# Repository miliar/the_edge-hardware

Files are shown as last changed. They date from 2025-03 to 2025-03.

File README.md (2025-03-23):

# The Edge - Hardware

This repository contains the hardware implementation of The Edge, a BLE-enabled weight sensor designed specifically for climbing training.

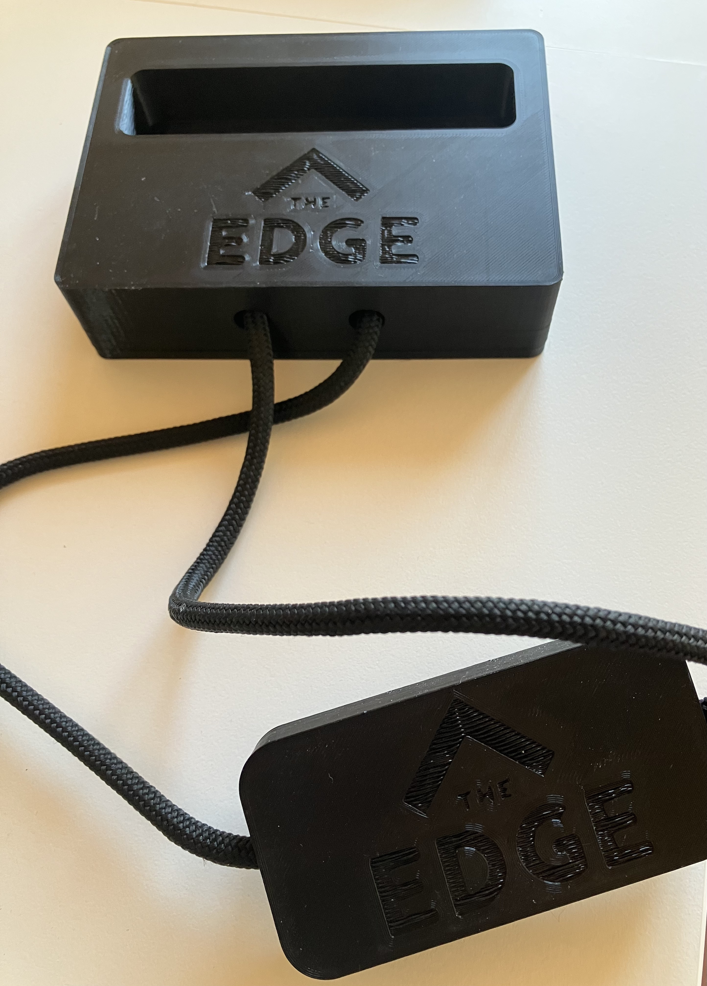
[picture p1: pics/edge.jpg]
The Edge Device


## Project Overview

```mermaid
graph LR
    A[The Edge Hardware] --> |BLE| B[The Edge - Climbing Game]
    subgraph Hardware
        C[Load Cell Sensor] --> A
        E[ESP32-S3 Controller] --> A
    end
    subgraph Mobile App
        B --> F[Game Interface]
        B --> G[Training Stats]
        B --> H[Level Editor]
    end
```

## Project Structure

- [/board](board/README.md) - Hardware assembly instructions and component list
- [/microcontroller](microcontroller/README.md) - Firmware implementation and setup guide
- [/python_cli_app](python_cli_app/README.md) - Test utility (for development use)

## Mobile Application

The Edge hardware connects to "The Edge - Climbing Game" mobile application (available for iOS and Android), which transforms your climbing training into an interactive gaming experience. The app features real-time strength feedback, a progressive level system, and custom level creation capabilities, allowing you to turn training protocols into engaging challenges.

### App Demo

Check out the app in action:

<a href="https://youtube.com/shorts/Y2iQzmk7Qgc" target="_blank">
    
</a>

### App Screenshots

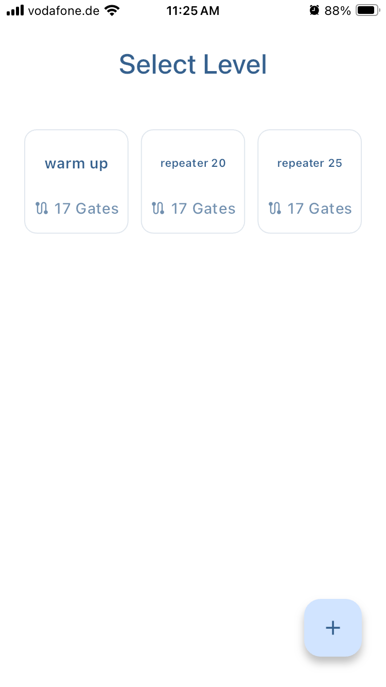
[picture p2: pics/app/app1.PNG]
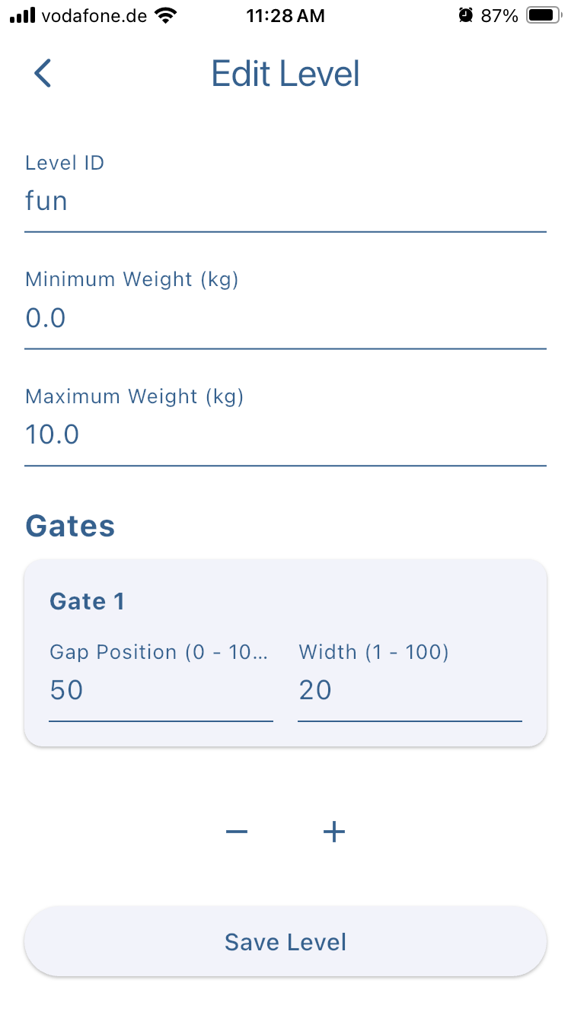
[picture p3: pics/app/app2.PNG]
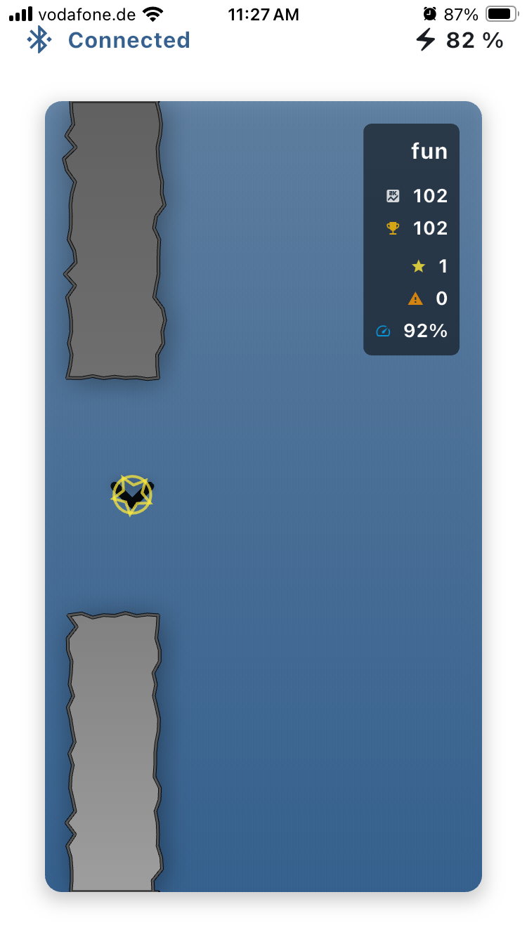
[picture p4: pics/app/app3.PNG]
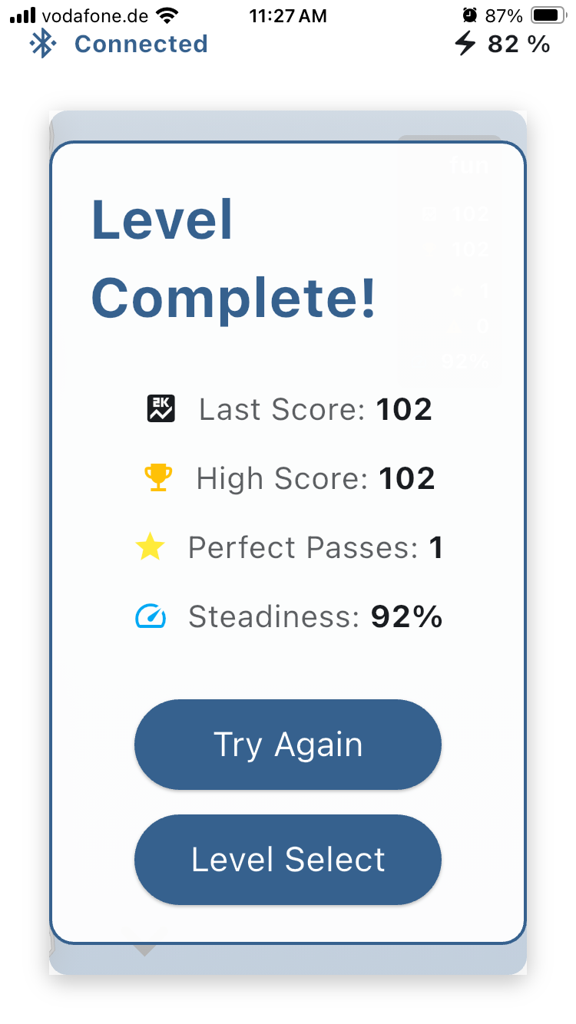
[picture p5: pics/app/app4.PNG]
   

## Getting Started

1. Follow the [hardware assembly guide](board/README.md) to build the device
2. Set up the [microcontroller firmware](microcontroller/README.md)
3. Install The Edge - Climbing Game from your device's app store:

   | App Store | Play Store |
   |:-:|:-:|
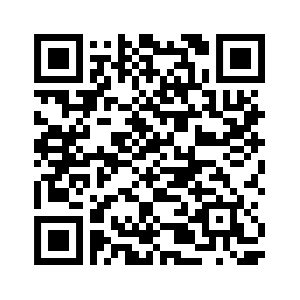
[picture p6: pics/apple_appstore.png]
App Store QR Code
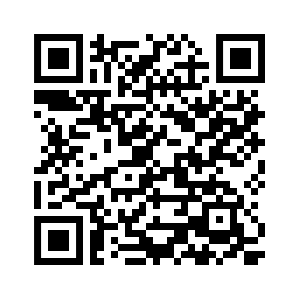
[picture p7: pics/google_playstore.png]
Play Store QR Code
   |  |  |

4. Connect the app to your Edge hardware via Bluetooth
5. Start training!

## Repository Contents

- `board/` - 3D models, assembly instructions, and parts list
- `microcontroller/` - CircuitPython firmware and configuration
- `pics/` - Project documentation images
- `python_cli_app/` - Test utility (for development use)

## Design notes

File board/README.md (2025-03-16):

# Project Components

## Required Parts

- QT Py S3 8MB (No PSRAM)
  - [Purchase Link](https://www.adafruit.com/product/5426)
  - [Pinout Documentation](https://learn.adafruit.com/adafruit-qt-py-esp32-s3/pinouts)

  

- LiPo Backpack
  - [Purchase Link](https://www.adafruit.com/product/5397)
  - [Pinout Documentation](https://learn.adafruit.com/adafruit-qt-py-charger-bff/pinouts)

  

- 2x3 2.54mm SMD Female Connector

  

- NAU7802 ADC
  - [Purchase Link](https://www.adafruit.com/product/4538)
  - [Documentation](https://learn.adafruit.com/adafruit-nau7802-24-bit-adc-stemma-qt-qwiic/python-circuitpython)
  - [Example Code](https://github.com/adafruit/CircuitPython_NAU7802/blob/main/examples/nau7802_simpletest.py)

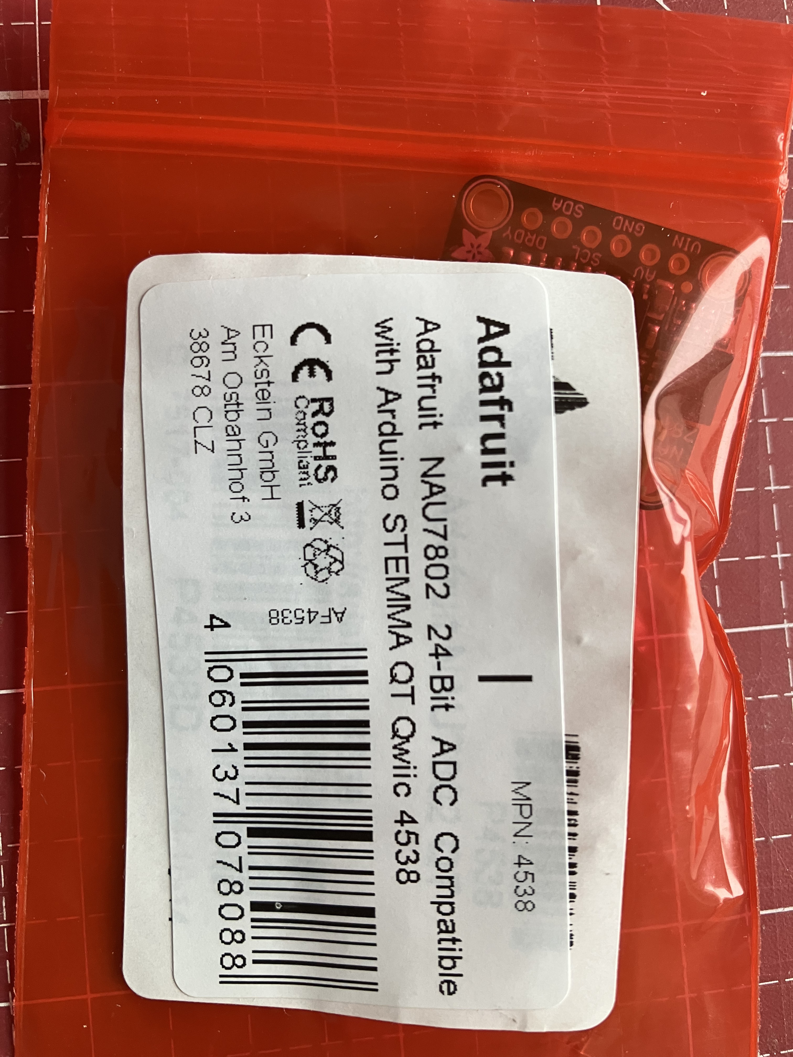
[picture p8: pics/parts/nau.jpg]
  

- LiPo Battery
  - Specifications: 3.7V 350mAh with JST-PHR-2 Connector (LP552035)

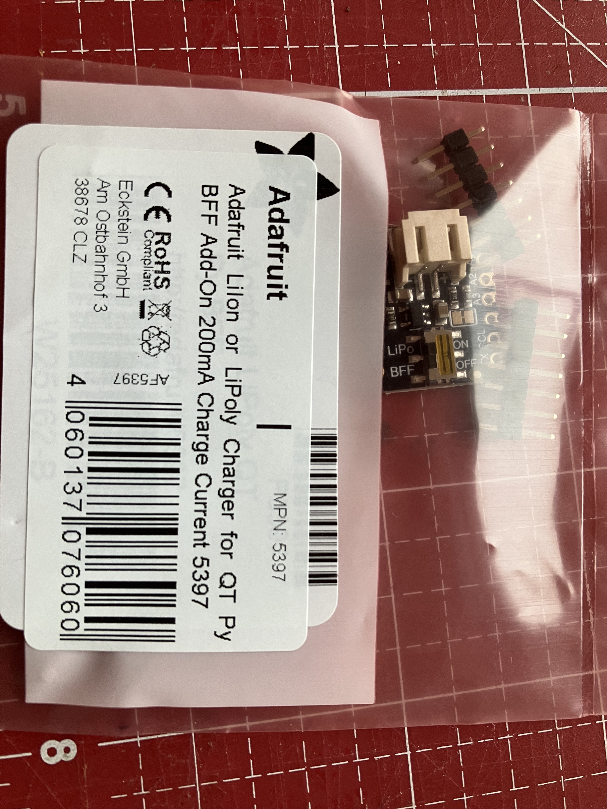
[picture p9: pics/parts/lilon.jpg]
  

- Load Cell
  - Specifications: 25mm 0-200kg (Model: cn1501541594)
  - Manufacturer: XNQ Electric Company Store
  - [Purchase Link](https://www.aliexpress.com/item/33014551751.html)

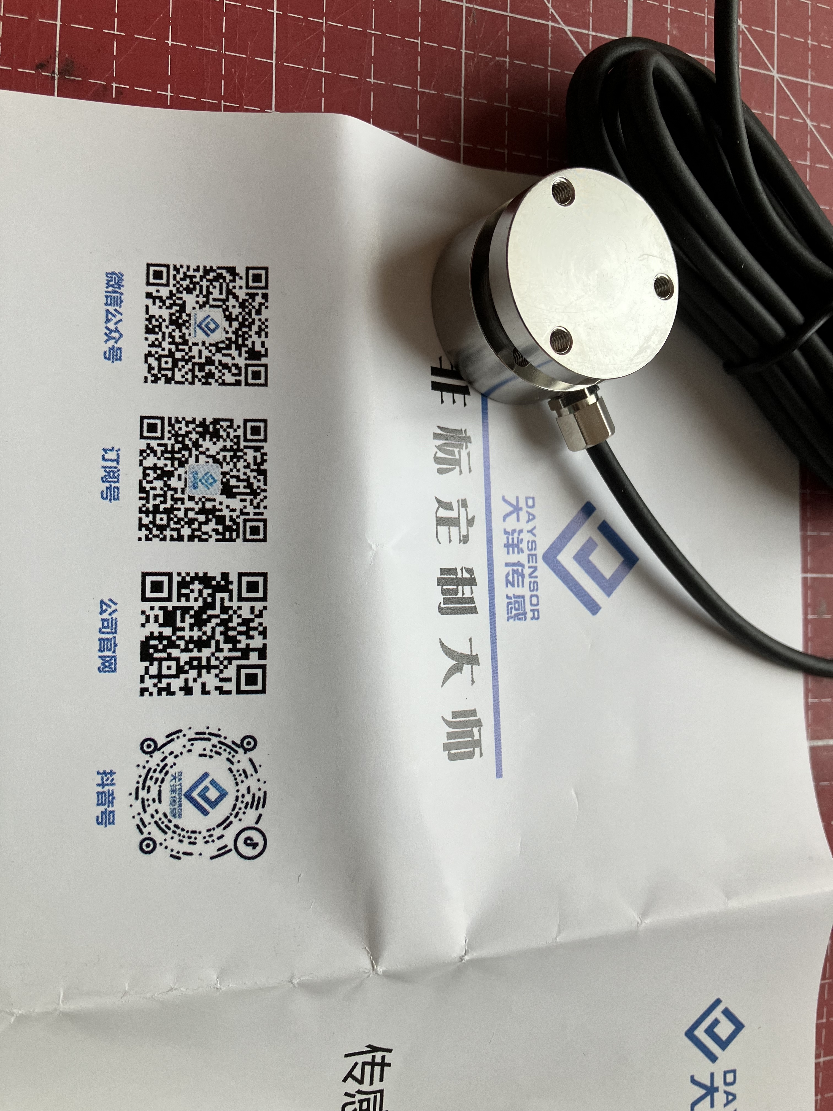
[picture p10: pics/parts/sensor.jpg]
  

- 3x M3 10mm Screws

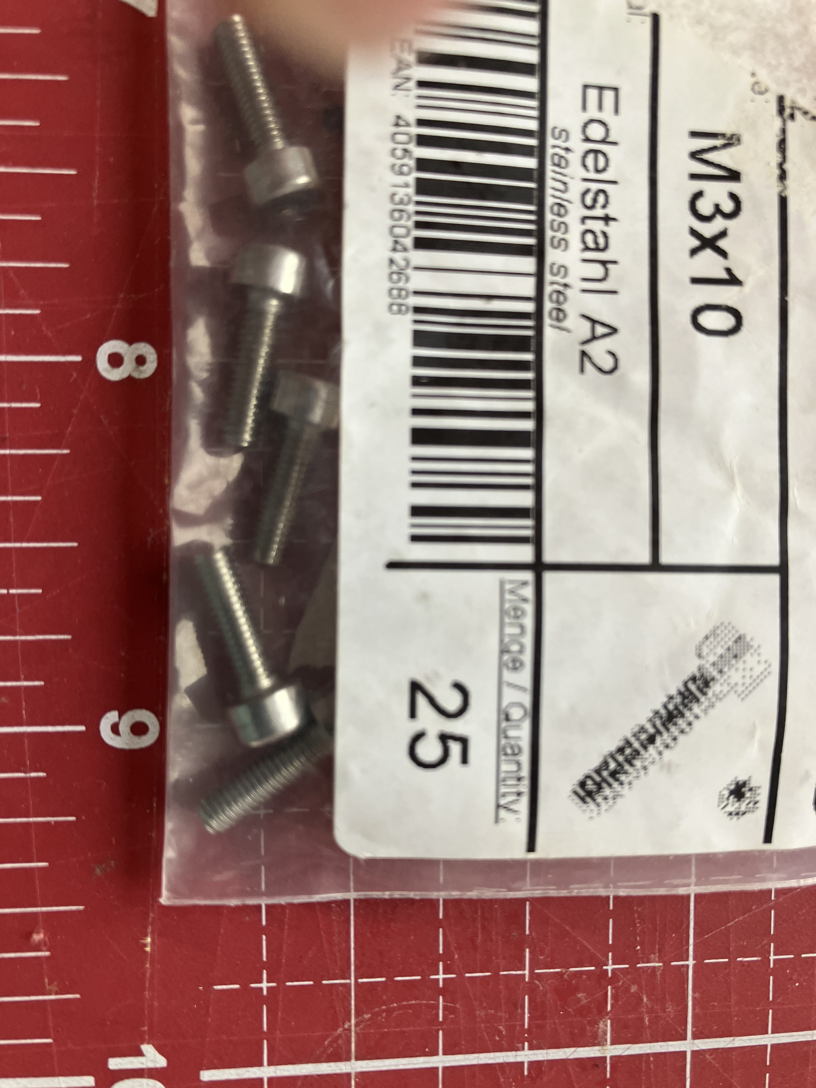
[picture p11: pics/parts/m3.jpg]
  

- STEMMA QT/Qwiic JST SH 4-Pin Cable (≥50mm)

  

- USB-C Connector (7x12x26mm)
  - [Purchase Link](https://www.amazon.de/dp/B0BNNJ5RTG)

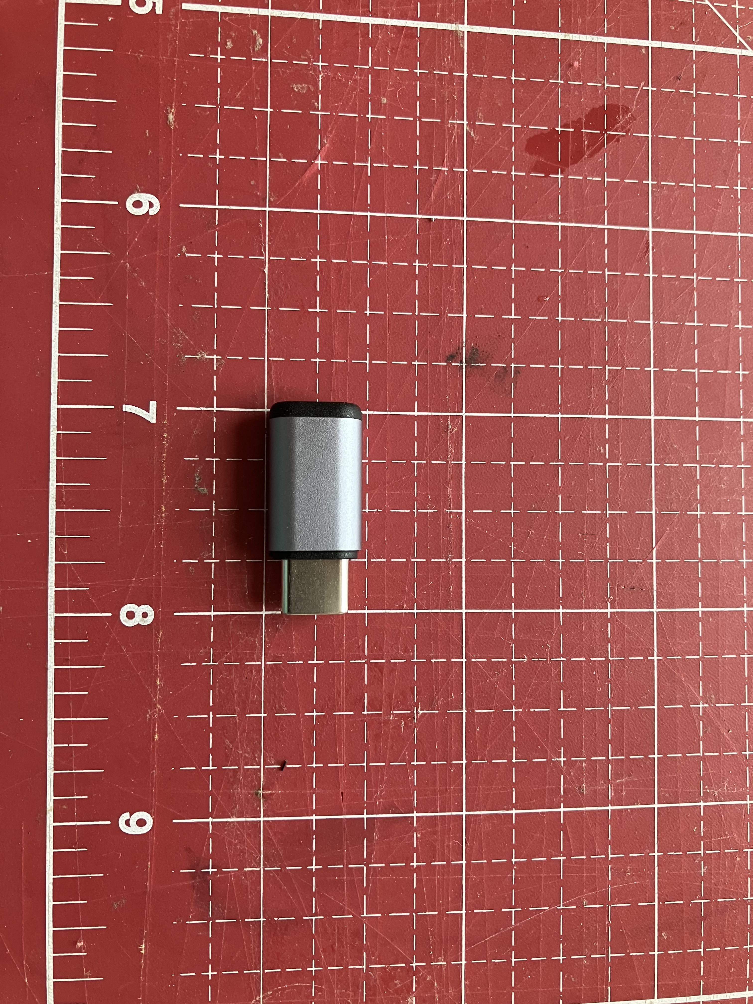
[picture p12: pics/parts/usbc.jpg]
  

- Rope (6mm diameter, ca 1m length)

- Slide Switch with Cables
  - [Purchase Link](https://eckstein-shop.de/PololuMiniSlideSwitch3A3-Pin2CSPDT2C03A3-PackEN)

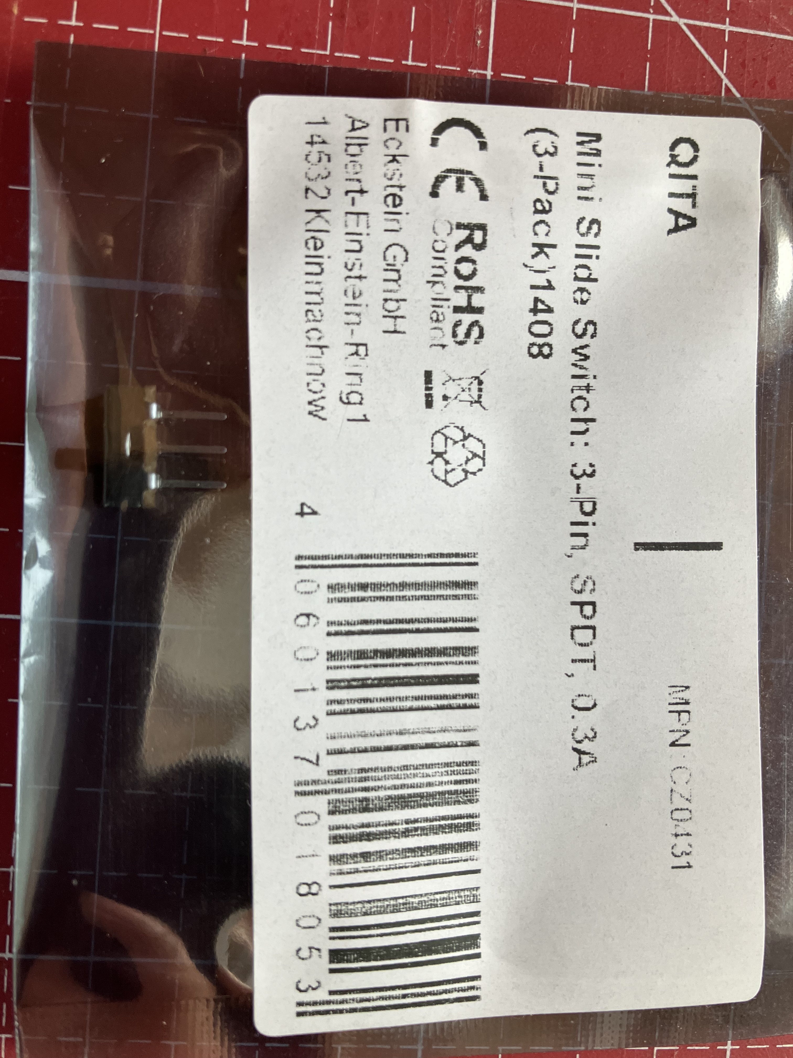
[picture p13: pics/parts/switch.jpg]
  

- 4x Screws (3x12mm)

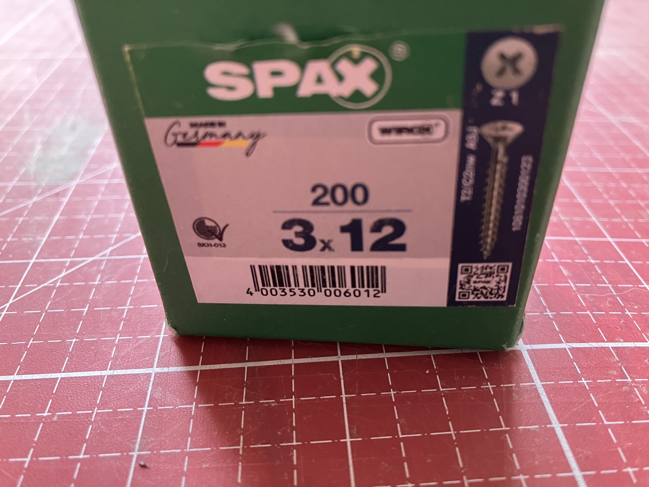
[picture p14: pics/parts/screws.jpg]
  

- 3D Printed Parts in PETG:
  - Use 0.26 mm layer height, 4 perimeters, 50 percent infill
  - Set bridge angle to 90 degrees
  - Enable support for the edge

  

## Board Assembly Instructions

### Soldering Steps
1. Remove the existing switch from the LiPo backpack using hot air (350°C)
2. Solder the 3x2 female connector onto the board using hot air or reflow soldering

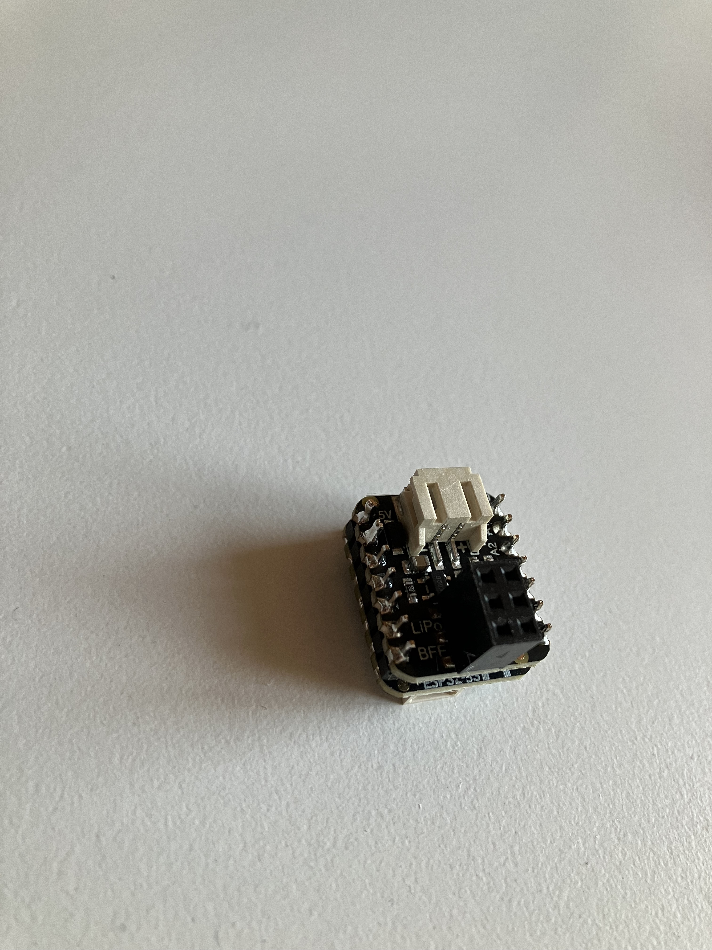
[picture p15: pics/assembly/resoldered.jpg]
   

3. Solder the LiPo backpack to the QT Py S3
4. Prepare two 4cm cables with crimped ends and connect them between the 3x2 connector and the slide switch

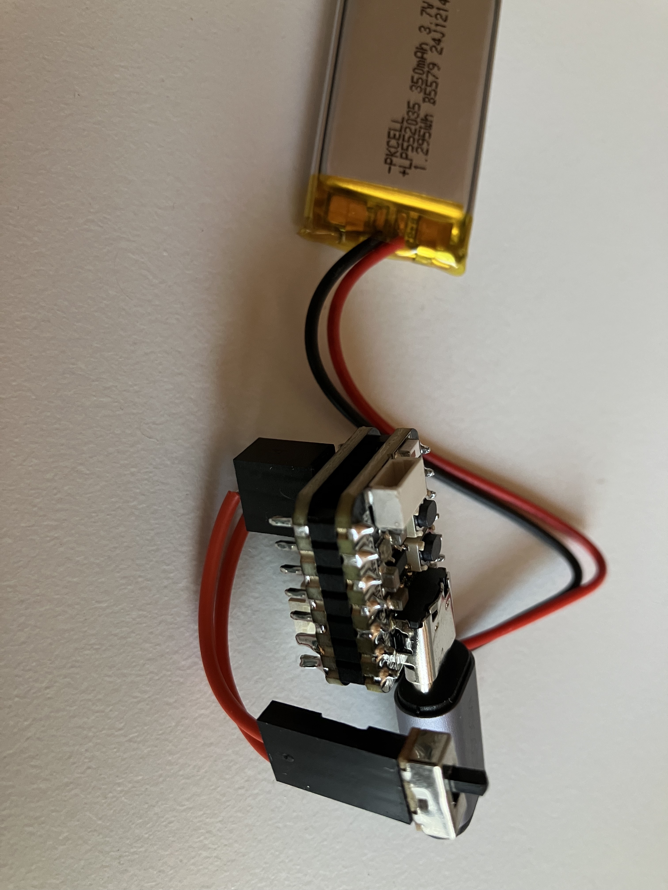
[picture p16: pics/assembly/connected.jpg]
   

### Sensor Cable Preparation
1. Cut the load cell sensor cable to 7cm length
2. Carefully remove the outer insulation and shielding
3. Strip approximately 2cm of insulation from each of the inner cables
4. Neatly twist and roll up the exposed cable ends to prevent fraying
5. Connect the prepared cables to the corresponding terminals on the NAU7802 ADC board

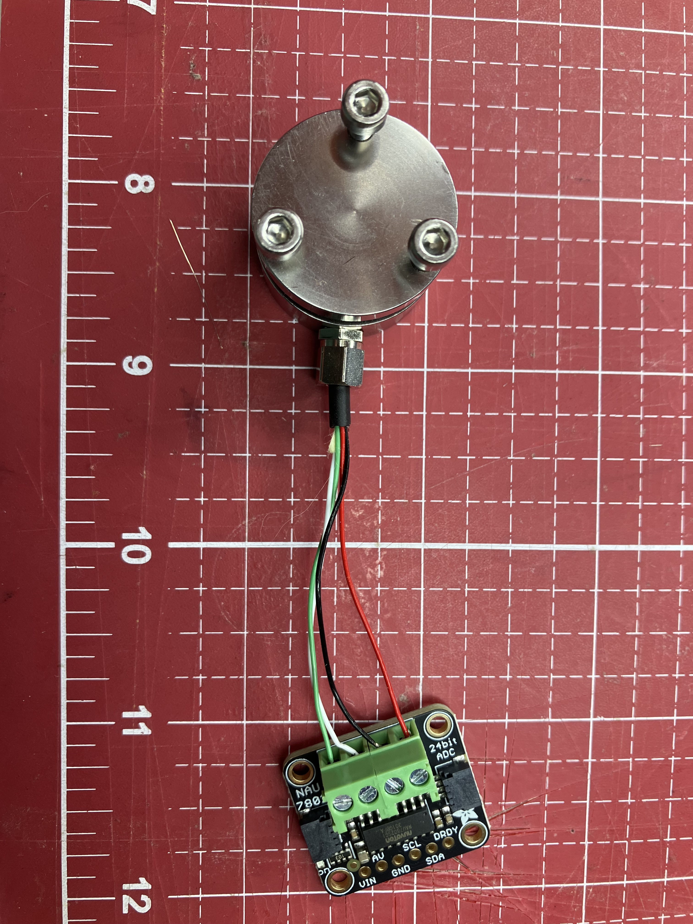
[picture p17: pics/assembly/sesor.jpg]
   

### Final Assembly
1. Insert the 3x M3 10mm screws into the load cell sensor mounting holes to secure the rope
2. Connect the NAU7802 to the QT Py using the STEMMA QT/Qwiic cable
3. Apply adhesive to mount the USB-C connector and slide switch in their designated positions
4. Ensure all components are securely mounted and connections are tight

   

### Info
- Battery Testing Results
  - Voltage: 2.9V under load, 3.6V from USB
  - Operating Time: 3.5 hours
  - Deep Sleep Mode: Battery did only last ~10 hours, so not used
- Adafruit QT Py ESP32-S3 Compatibility:
  - 4MB Flash 2MB PSRAM version not supported ("`no module named _bleio`")
  - Only 8MB No PSRAM version is supported
  - [Compatibility Matrix](https://docs.circuitpython.org/en/latest/shared-bindings/support_matrix.html)

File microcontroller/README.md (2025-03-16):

# Microcontroller Setup Guide

## Initial Setup
1. Factory reset the device
2. Install UF2 bootloader
   - Follow [QT Py ESP32-S3 CircuitPython Guide](https://learn.adafruit.com/adafruit-qt-py-esp32-s3/circuitpython-2)
   - Use [Adafruit Web Serial ESPTool](https://adafruit.github.io/Adafruit_WebSerial_ESPTool/) for flashing

## File Deployment
Copy all files from the `microcontroller/` directory to the device, **excluding** the `setup_circuitpython/` folder.

## Directory Structure
```
microcontroller/
├── code.py                 # Main program file
├── ble_json_service.py     # BLE service implementation
├── config.json             # User configuration file
├── default_config.json     # Default configuration file
└── lib/                    # Required libraries
    ├── adafruit_ble/
    ├── adafruit_bus_device/
    ├── adafruit_register/
    ├── adafruit_pixelbuf.mpy
    ├── cedargrove_nau7802.mpy
    └── neopixel.mpy
```

## Operation Guide

### Serial Console Output
To monitor the serial output while usb-c connected:

1. Find the device ID:
```bash
ls /dev/tty.*
```

2. Connect to the serial console:
```bash
screen [device_id]
```

For more information on using the serial console, see the [CircuitPython Advanced Serial Console Guide](https://learn.adafruit.com/welcome-to-circuitpython/advanced-serial-console-on-mac-and-linux)

### LED Status Indicators
The onboard NeoPixel LED indicates the device's current status:
- Red: Error state or initializing
- Yellow: Waiting for BLE connection
- Green: Connected to a BLE device

### Sensor Functionality
The device provides two sensor measurements:
1. **Weight Sensor**: Uses the NAU7802 load cell amplifier to measure weight. The raw values are averaged over multiple samples (configurable) and scaled according to the configuration.
2. **Voltage Sensor**: Reads analog voltage from pin A2, converts it to a percentage based on configured offset and scale factors.

### BLE Service
The device advertises a custom BLE service with the following characteristics:

1. **Sensors Characteristic** (Read-only)
   - UUID: 528ff74b-fdb8-444c-9c64-3dd5da4135ae
   - Provides real-time sensor data in JSON format:
     ```json
     {
       "weight": <value>,
       "voltage": "<percentage>%"
     }
     ```

2. **Settings Characteristic** (Read/Write)
   - UUID: e077bdec-f18b-4944-9e9e-8b3a815162b4
   - Allows reading and updating device settings

### Configuration
The device uses a configuration file (`config.json`) with fallback to `default_config.json`. Configuration options include:
- `device_name`: BLE advertisement name
- `weight_samples`: Number of samples to average for weight measurement
- `weight_scale_factor`: Scaling factor for weight measurements
- `voltage`: Configuration for voltage sensor:
  - `offset`: Voltage reading offset
  - `scale_factor`: Voltage scaling factor

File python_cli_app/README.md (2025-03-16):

# Python CLI Application Guide
This is a test utility for The Edge hardware that allows you to:
- Scan for available Edge devices
- Connect to a selected device
- Monitor real-time weight measurements
- View battery status
- Track maximum weight (high score)

## Running the Application
```bash
python python_cli_app/ble_json_central.py
```

## Example Output
```
Scanning for Edge devices...
Found device: myedgedewood
Services: <BoundServiceList: 51ad213f-e568-4e35-84e4-67af89c79ef0>
Found device: myedgedevice
Services: <BoundServiceList: 51ad213f-e568-4e35-84e4-67af89c79ef0>

Available devices:
1: myedgedewood
2: myedgedevice

Select device (1-2) or 'r' to rescan: 2
Connected!
{'voltage': '75 %', 'weight': 1566}
{'voltage': '77 %', 'weight': 2344}
{'voltage': '76 %', 'weight': 3869}
{'voltage': '76 %', 'weight': 5126}
{'voltage': '76 %', 'weight': 5362}
{'voltage': '77 %', 'weight': 3700}
{'voltage': '76 %', 'weight': 1503}
High score: 6.37 kg
Last score: 5.126 kg
Power: 77 %
```

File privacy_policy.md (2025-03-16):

# Privacy Policy

Last updated: March 14, 2025

## Introduction

This Privacy Policy describes how your data is handled when using my app. I am committed to protecting your privacy and being transparent about my practices.

## Information Collection

I do not collect, store, or transmit any personal information. All data generated while using the app (such as game progress and settings) is stored locally on your device only and is not transmitted to any external servers.

## Device Permissions

### Bluetooth Access
The app requires Bluetooth permission to connect to compatible hardware devices. This connection is used solely for device communication and no Bluetooth-related data is collected or stored beyond the current session.

## Data Storage

- All app data is stored locally on your device
- No data is transmitted to external servers
- No analytics or usage data is collected
- No crash reports are collected
- No third-party services are used

## Changes to Data

Since all data is stored locally on your device, you can clear the app's data through your device's settings at any time.

## Children's Privacy

My app does not knowingly collect any personal information from anyone, including children under the age of 13.

## Third-Party Services

I do not use any third-party services, analytics, or tracking tools.

## Changes to Privacy Policy

I may update this Privacy Policy from time to time. I will notify you of any changes by posting the new Privacy Policy on this page and updating the "Last updated" date at the top.

## Contact

If you have any questions about this Privacy Policy, please contact me at via issues.

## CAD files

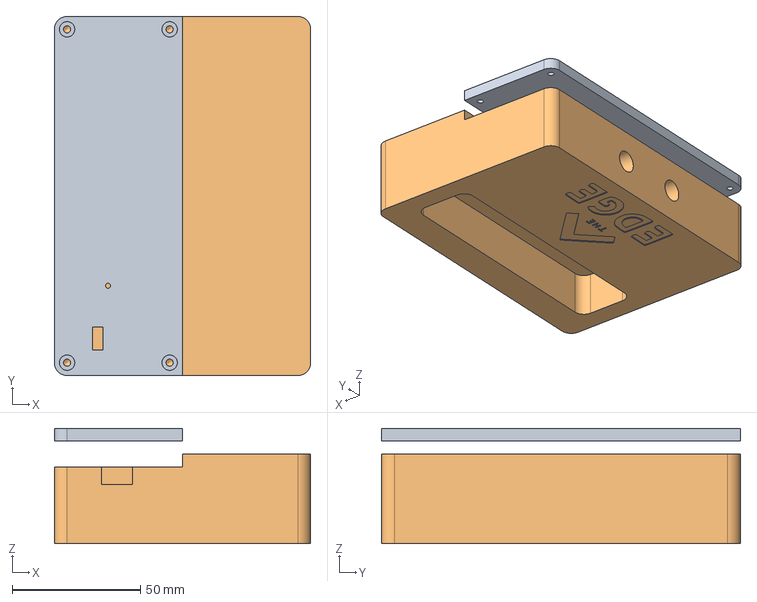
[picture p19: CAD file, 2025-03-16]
board/corpus.step
100.0 x 140.0 x 45.0 mm

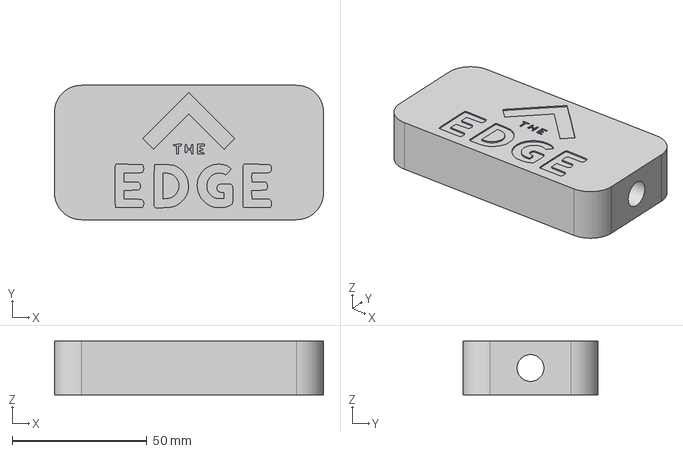
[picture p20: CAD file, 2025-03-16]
board/footpad.step
100.0 x 50.0 x 20.0 mm

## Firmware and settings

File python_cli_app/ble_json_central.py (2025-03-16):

from ble_json_service import SensorService
from adafruit_ble import BLERadio
from adafruit_ble.advertising.standard import ProvideServicesAdvertisement


class BLEController:
    WEIGHT_THRESHOLD = 1000  # Threshold in grams
    SCAN_TIMEOUT = 5.0  # Scanning timeout in seconds

    def __init__(self):
        self.ble = BLERadio()
        self.connection = None
        self.high_score = 0
        self.last_score = 0
        self.last_score_toggle = True

    def scan_for_devices(self):
        """Scan for available Edge devices and return list of advertisements."""
        print("Scanning for Edge devices...")
        devices = []
        try:
            for advertisement in self.ble.start_scan(
                ProvideServicesAdvertisement, timeout=self.SCAN_TIMEOUT
            ):
                if SensorService in advertisement.services:
                    if advertisement not in devices:
                        print(f"Found device: {advertisement.complete_name}")
                        print(f"Services: {advertisement.services}")
                        devices.append(advertisement)
        finally:
            self.ble.stop_scan()
        return devices

    def select_device(self, devices):
        """Let user select a device from the list of found devices."""
        if not devices:
            print("No Edge devices found!")
            return None

        print("\nAvailable devices:")
        for i, device in enumerate(devices, 1):
            name = (
                device.complete_name
                if device.complete_name
                else f"Edge Device {device.address}"
            )
            print(f"{i}: {name}")

        while True:
            try:
                choice = input(
                    "\nSelect device (1-{}) or 'r' to rescan: ".format(len(devices))
                )
                if choice.lower() == "r":
                    return None
                choice = int(choice)
                if 1 <= choice <= len(devices):
                    return devices[choice - 1]
                print(
                    f"Invalid choice. Please select a number between 1 and {len(devices)}"
                )
            except ValueError:
                print("Invalid input. Please enter a number or 'r'")

    def _handle_disconnected_state(self):
        """Handle device discovery and connection when disconnected."""
        devices = self.scan_for_devices()
        selected_device = self.select_device(devices)
        if selected_device:
            try:
                self.connection = self.ble.connect(selected_device)
                print("Connected!")
            except Exception as e:
                print(f"Failed to connect: {e}")
                self.connection = None
        else:
            print("\nScanning again...")

    def run(self):
        """Main loop for handling BLE connections and data."""
        while True:
            try:
                if not self.connection or not self.connection.connected:
                    self._handle_disconnected_state()
                    continue

                service = self.connection[SensorService]
                self.process_sensor_data(service)

            except Exception as e:
                print(f"Error: {e}")
                self.connection = None

    def _handle_active_weight(self, service):
        if self.last_score_toggle:
            self.last_score_toggle = False
            self.last_score = 0
        print(service.sensors)
        self.high_score = max(service.sensors.get("weight", 0), self.high_score)
        self.last_score = max(service.sensors.get("weight", 0), self.last_score)

    def _handle_inactive_weight(self, service):
        if not self.last_score_toggle:
            print(f"High score: {self.high_score / 1000} kg")
            print(f"Last score: {self.last_score / 1000} kg")
            print(f"Power: {service.sensors.get('voltage', '?')}")
            self.last_score_toggle = True

    def process_sensor_data(self, service):
        if service.sensors and service.sensors.get("weight", 0) > self.WEIGHT_THRESHOLD:
            self._handle_active_weight(service)
        else:
            self._handle_inactive_weight(service)


if __name__ == "__main__":
    controller = BLEController()
    controller.run()

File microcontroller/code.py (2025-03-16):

import json
from ble_json_service import SensorService
from adafruit_ble import BLERadio
from adafruit_ble.advertising.standard import ProvideServicesAdvertisement
from cedargrove_nau7802 import NAU7802
import board
import neopixel
import analogio


class LEDColors:
    ERROR = (255, 0, 0)
    WAITING = (255, 255, 0)
    CONNECTED = (0, 100, 0)


def load_config():
    """Load configuration from config.json file, falling back to default_config.json"""
    try:
        with open("config.json", "r") as f:
            return json.load(f)
    except (OSError, ValueError):
        with open("default_config.json", "r") as f:
            return json.load(f)


def zero_channel(nau):
    """Initiate internal calibration for current channel.Use when scale is started,
    a new channel is selected, or to adjust for measurement drift. Remove weight
    and tare from load cell before executing."""
    print(f"channel {nau.channel} calibrate.INTERNAL: {nau.calibrate('INTERNAL'):>5}")
    print(f"channel {nau.channel} calibrate.OFFSET:   {nau.calibrate('OFFSET'):>5}")
    print(f"...channel {nau.channel} zeroed")


def get_weight(nau, config):
    """Read and average consecutive raw sample values. Return average raw value."""
    sample_sum = 0
    for _ in range(config["weight_samples"]):
        while not nau.available():
            pass
        sample_sum += nau.read()
    return int((sample_sum / config["weight_samples"]) / config["weight_scale_factor"])


def get_voltage(pin, config):
    voltage_config = config["voltage"]
    return f"{int((pin.value - voltage_config['offset']) / voltage_config['scale_factor'])} %"


if __name__ == "__main__":
    print("Remove weights from load cell")
    pixel = neopixel.NeoPixel(board.NEOPIXEL, 1)
    pixel.fill(LEDColors.ERROR)
    config = load_config()
    ble = BLERadio()
    ble.name = config["device_name"]
    service = SensorService()
    advertisement = ProvideServicesAdvertisement(service)
    nau7802 = NAU7802(board.STEMMA_I2C(), address=0x2A, active_channels=1)
    enabled = nau7802.enable(True)
    zero_channel(nau7802)
    analog_pin = analogio.AnalogIn(board.A2)
    print("Ready")

    while True:
        pixel.fill(LEDColors.WAITING)
        print("Advertise services")
        ble.stop_advertising()
        print(f"Advertising with name: {ble.name}")
        print(f"Advertisement: {advertisement}")
        ble.start_advertising(advertisement)
        print("Waiting for connection...")

        while not ble.connected:
            pass

        print("Connected")
        pixel.fill(LEDColors.CONNECTED)
        while ble.connected:
            measurement = {
                "weight": get_weight(nau7802, config),
                "voltage": get_voltage(analog_pin, config),
            }
            service.sensors = measurement
            print(f"Sensors: {measurement}")
        print("Disconnected")
